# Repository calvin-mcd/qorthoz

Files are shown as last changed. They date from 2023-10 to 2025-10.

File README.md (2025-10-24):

# qorthoz

qorthoz is an ortholinear 10.25u qaz compatible pcb with usb c and jst ports for case compatibility, rgb breakout strip and 6 additional pins for switch or rotary extensions.

## Layout

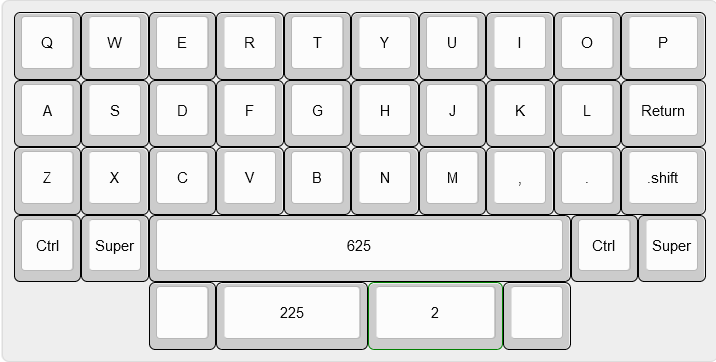
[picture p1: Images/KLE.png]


## Pictures

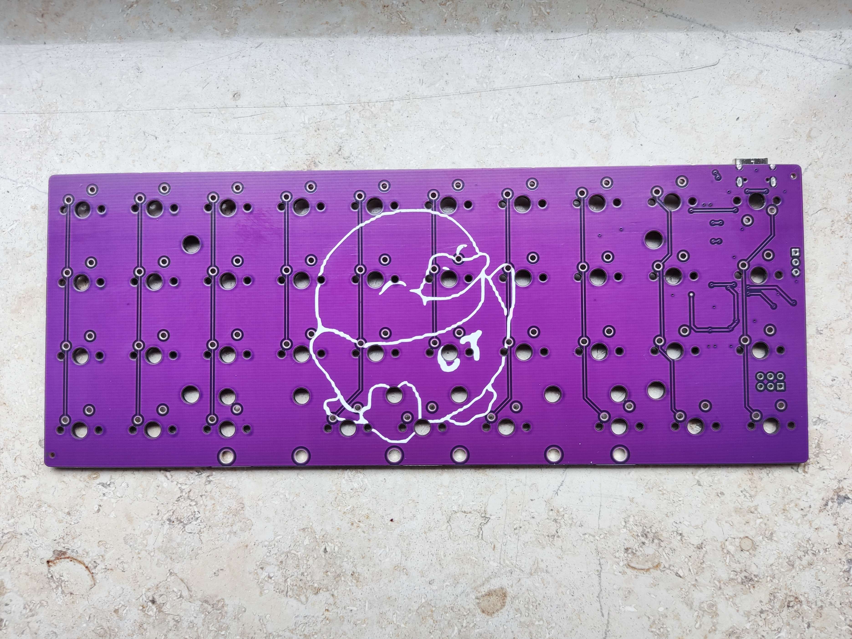
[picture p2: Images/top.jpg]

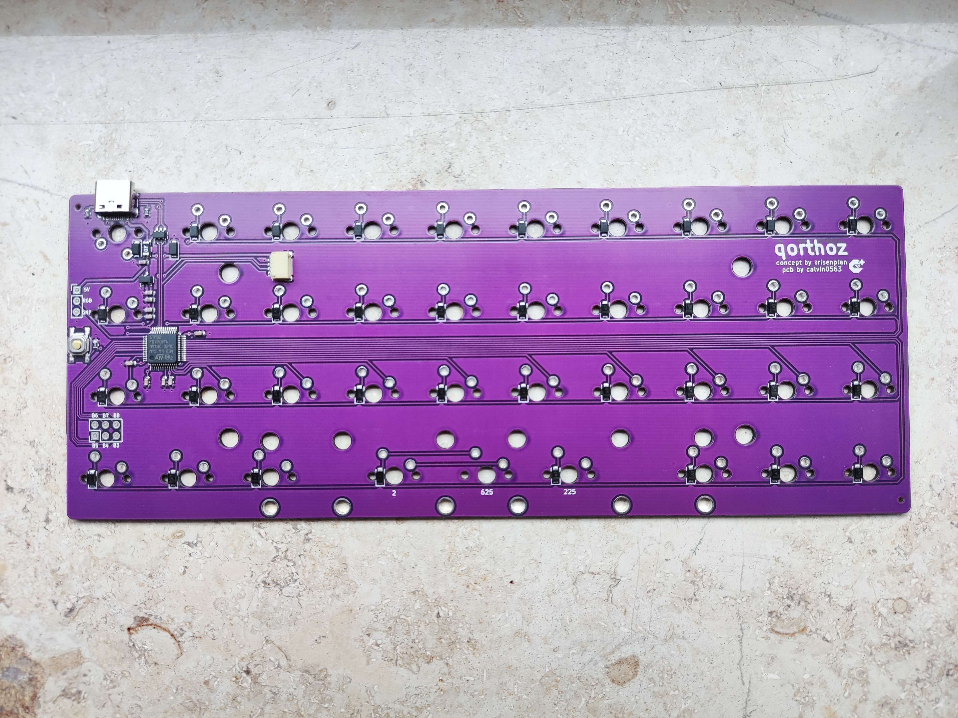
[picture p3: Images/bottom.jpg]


## Firmware

Firmware is written for vial and the source code is provided for edits.

## RGB Strip

Please note that the PCB is using a STM32 MCU which runs on 3v3 logic. Using a 5V rgb strip can sometimes interfere with the 3v3 Data Signal from the MCU. If you use a 5V rgb strip solder Data IN and GND to the beginning of the strip but *DO NOT* solder power to the beginning but anywhere else on the strip. This should be enough to avoid 5V Power interference with the 3v3 Data IN.

## Disclaimer

This PCB has been fully tested and is confirmed to work. However, no-one involved in this project is responsible for any usage issues that may arise. Order at your own risk. Feel free to edit, modify and otherwise utilise these files.

## License

This project is released under the GPL v3 License. Please refer to the LICENCE file.

## Credits

This pcb has been made on request kriscovery. Do check out their beautiful qaz and qez compatible cases! https://www.printables.com/@kriscovery

The silkscreen logo has been taken from the german 40s keyboard discord ClackTales!

As always big thanks to the many people who helped me and inspired this board!

Any questions, contact Calvin0563 on Discord.

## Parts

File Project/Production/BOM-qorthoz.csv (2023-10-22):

Comment | Designator | Footprint | LCSC
SKQGABE010 | SW1 | SW_SPST_SKQG_WithoutStem | C115351
1uF | C1,C2,C4 | C_0603_1608Metric | C15849
JST SH | J3 | JST_SH_SM04B-SRSS-TB_1x04-1MP_P1.00mm_Horizontal | C160404
USB_C_Receptacle_USB2.0 | J1 | USB_C_Receptacle_HRO_TYPE-C-31-M-12 | C165948
4.7uF | C3 | C_0603_1608Metric | C19666
10k | R3 | R_0603_1608Metric | C2139679
5k1 | R1,R2 | R_0603_1608Metric | C14677
USBLC6-2SC6 | U1 | SOT-23-6 | C2827654
100nF | C10,C5,C6,C7,C8,C9 | C_0603_1608Metric | C14663
XC6206PxxxMR-Regulator_Linear | U3 | SOT-23 | C5446
D_Small | D1,D10,D11,D12,D13,D14,D15,D16,D17,D18,D19,D2,D20,D21,D22,D23,D24,D25,D26,D27,D28,D29,D3,D30,D31,D32,D33,D34,D35,D36,D37,D38,D4,D5,D6,D7,D8,D9 | D_SOD-123F | C64898
500mA | F1 | Fuse_1206_3216Metric | C70076
SMF9.0CA | D_PWR1 | D_SOD-123 | C707469
STM32F072C8Tx | U2 | LQFP-48_7x7mm_P0.5mm | C81720

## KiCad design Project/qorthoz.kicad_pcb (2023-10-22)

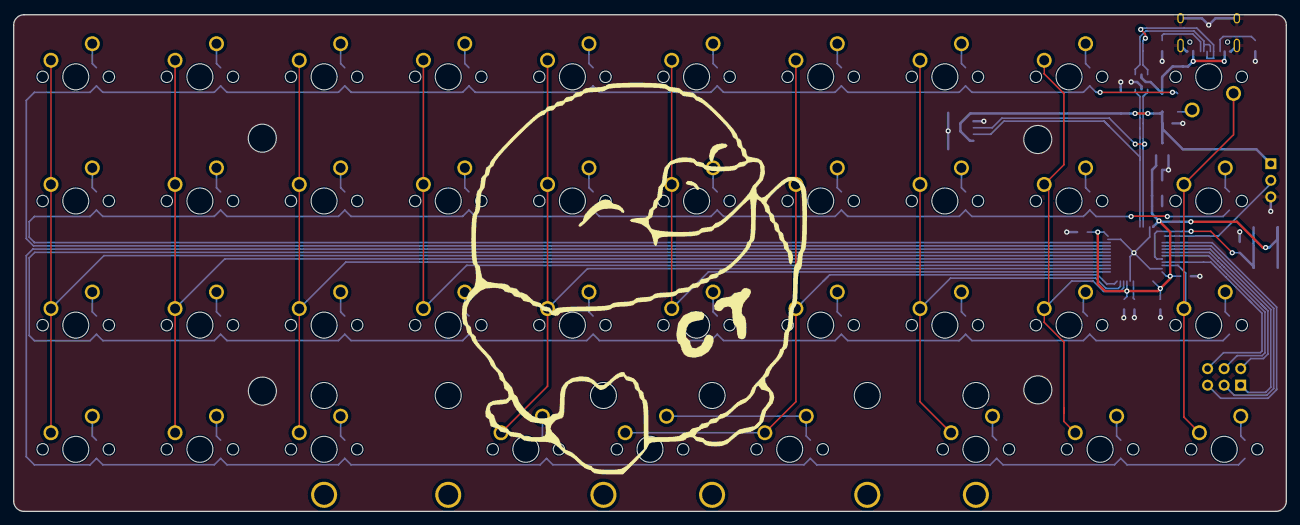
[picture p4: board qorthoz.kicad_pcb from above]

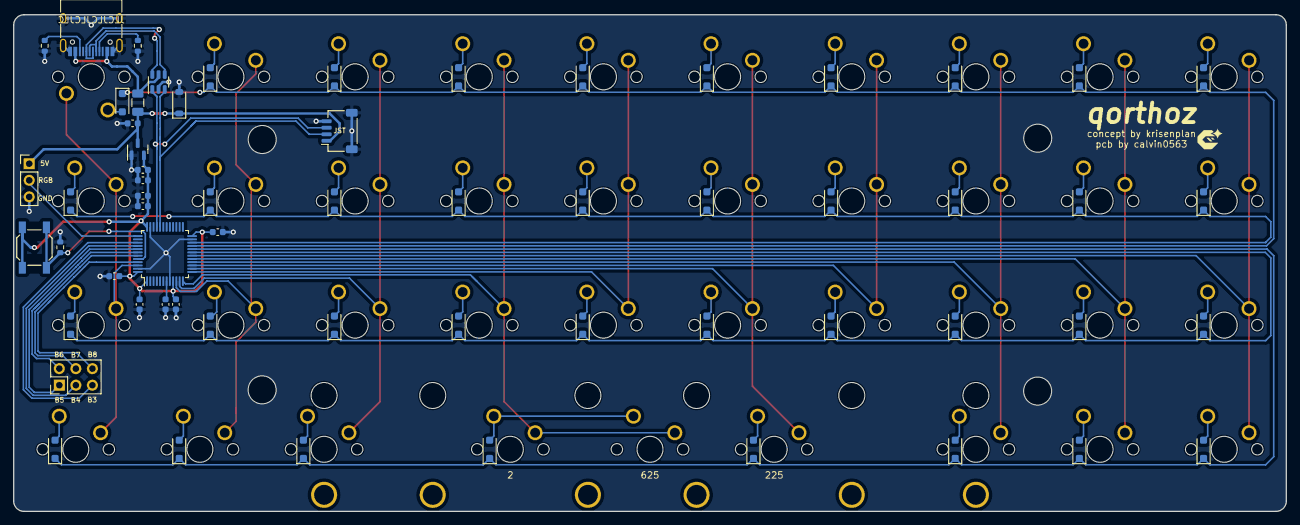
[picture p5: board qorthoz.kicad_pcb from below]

Board: 2 copper layers, 195.3 x 76.2 mm, 103 parts (61 on the bottom side), 71 nets.

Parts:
C1, C2, C4: 1uF; C_0603_1608Metric
C3: 4.7uF; C_0603_1608Metric
C5, C6, C7, C8, C9, C10: 100nF; C_0603_1608Metric
D1, D2, D3, D4, D5, D6, D7, D8, D9, D10, D11, D12, D13, D14, D15, D16, D17, D18, D19, D20, D21, D22, D23, D24, D25, D26, D27, D28, D29, D30, D31, D32, D33, D34, D35, D36, D37, D38: D_Small; D_SOD-123F
D_PWR1: SMF9.0CA; D_SOD-123
F1: 500mA; Fuse_1206_3216Metric
J1: USB_C_Receptacle_USB2.0; USB_C_Receptacle_HRO_TYPE-C-31-M-12
J2: Conn_01x03_Socket; PinHeader_1x03_P2.54mm_Vertical
J3: JST SH; JST_SH_SM04B-SRSS-TB_1x04-1MP_P1.00mm_Horizontal
J4: Conn_01x06; PinHeader_2x03_P2.54mm_Vertical
MX1, MX2, MX3, MX4, MX5, MX6, MX7, MX8, MX9, MX11, MX12, MX13, MX14, MX15, MX16, MX17, MX18, MX19, MX21, MX22, MX23, MX24, MX25, MX26, MX27, MX28, MX29, MX31, MX32, MX33, MX34, MX35, MX36, MX37, MX38, MX39: MX_SW_solder; SW_MX_1u
MX10, MX20, MX30: MX_SW_solder; SW_MX_1.25u
R1, R2: 5k1; R_0603_1608Metric
R3: 10k; R_0603_1608Metric
S1: MX_stab; STAB_MX_P_2.25u
S2: MX_stab; STAB_MX_P_2u
S3: MX_stab; STAB_MX_P_6.25u
SW1: SKQGABE010; SW_SPST_SKQG_WithoutStem
U1: USBLC6-2SC6; SOT-23-6
U2: STM32F072C8Tx; LQFP-48_7x7mm_P0.5mm
U3: XC6206PxxxMR-Regulator_Linear; SOT-23

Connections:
+3V3: C2.2, C3.1, C4.1, C5.1, C6.1, C7.1, C8.1, C9.1, SW1.1, U2.1 (VBAT), U2.9 (VDDA), U2.24 (VDD), U2.36 (VDDIO2), U2.48 (VDD), U3.2 (VO)
+5V: C1.2, D_PWR1.1 (A1), F1.2, J2.1, J3.1, U3.3 (VI)
/CC1: J1.A5 (CC1), R1.1
/CC2: J1.B5 (CC2), R2.1
B3: J4.5, U2.39 (PB3)
B4: J4.3, U2.40 (PB4)
B5: J4.1, U2.41 (PB5)
B6: J4.2, U2.42 (PB6)
B7: J4.4, U2.43 (PB7)
B8: J4.6, U2.45 (PB8)
BOOT0: R3.1, SW1.2, U2.44 (BOOT0)
COL0: MX1.1, MX11.1, MX21.1, MX31.1, U2.18 (PB0)
COL1: MX2.1, MX12.1, MX22.1, MX32.1, U2.17 (PA7)
COL2: MX3.1, MX13.1, MX23.1, MX33.1, U2.16 (PA6)
COL3: MX4.1, MX14.1, MX24.1, U2.15 (PA5)
COL4: MX5.1, MX15.1, MX25.1, MX34.1, U2.14 (PA4)
COL5: MX6.1, MX16.1, MX26.1, U2.13 (PA3)
COL6: MX7.1, MX17.1, MX27.1, MX35.1, MX39.1, U2.12 (PA2)
COL7: MX8.1, MX18.1, MX28.1, MX36.1, U2.11 (PA1)
COL8: MX9.1, MX19.1, MX29.1, MX37.1, U2.10 (PA0)
COL9: MX10.1, MX20.1, MX30.1, MX38.1, U2.46 (PB9)
D_N: J3.2, U1.3 (I/O2), U2.32 (PA11)
D_P: J3.3, U1.1 (I/O1), U2.33 (PA12)
D_USB_N: J1.A7 (D-), J1.B7 (D-), U1.4 (I/O2)
D_USB_P: J1.A6 (D+), J1.B6 (D+), U1.6 (I/O1)
GND: C1.1, C2.1, C3.2, C4.2, C5.2, C6.2, C7.2, C8.2, C9.2, C10.2, D_PWR1.2 (A2), J1.A1 (GND), J1.A12 (GND), J1.B1 (GND), J1.B12 (GND), J1.S1 (SHIELD), J2.3, J3.4, J3.MP (MountPin), R1.2, R2.2, R3.2, U1.2 (GND), U2.8 (VSSA), U2.23 (VSS), U2.35 (VSS), U2.47 (VSS), U3.1 (GND)
NRST: C10.1, U2.7 (NRST)
unnamed: D1.2 (A), MX1.2
unnamed: D2.2 (A), MX2.2
unnamed: D3.2 (A), MX3.2
unnamed: D4.2 (A), MX4.2
unnamed: D5.2 (A), MX5.2
unnamed: D6.2 (A), MX6.2
unnamed: D7.2 (A), MX7.2
unnamed: D8.2 (A), MX8.2
unnamed: D9.2 (A), MX9.2
unnamed: D10.2 (A), MX10.2
unnamed: D11.2 (A), MX11.2
unnamed: D12.2 (A), MX12.2
unnamed: D13.2 (A), MX13.2
unnamed: D14.2 (A), MX14.2
unnamed: D15.2 (A), MX15.2
unnamed: D16.2 (A), MX16.2
unnamed: D17.2 (A), MX17.2
unnamed: D18.2 (A), MX18.2
unnamed: D19.2 (A), MX19.2
unnamed: D20.2 (A), MX20.2
unnamed: D21.2 (A), MX21.2
unnamed: D22.2 (A), MX22.2
unnamed: D23.2 (A), MX23.2
unnamed: D24.2 (A), MX24.2
unnamed: D25.2 (A), MX25.2
unnamed: D26.2 (A), MX26.2
unnamed: D27.2 (A), MX27.2
unnamed: D28.2 (A), MX28.2
unnamed: D29.2 (A), MX29.2
unnamed: D30.2 (A), MX30.2
unnamed: D31.2 (A), MX31.2
unnamed: D32.2 (A), MX32.2
unnamed: D33.2 (A), MX33.2
unnamed: D34.2 (A), MX34.2
unnamed: D35.2 (A), MX35.2, MX39.2
unnamed: D36.2 (A), MX36.2
unnamed: D37.2 (A), MX37.2
unnamed: D38.2 (A), MX38.2
RGB: J2.2, U2.37 (PA14)
ROW0: D1.1 (K), D2.1 (K), D3.1 (K), D4.1 (K), D5.1 (K), D6.1 (K), D7.1 (K), D8.1 (K), D9.1 (K), D10.1 (K), U2.21 (PB10)
ROW1: D11.1 (K), D12.1 (K), D13.1 (K), D14.1 (K), D15.1 (K), D16.1 (K), D17.1 (K), D18.1 (K), D19.1 (K), D20.1 (K), U2.22 (PB11)
ROW2: D21.1 (K), D22.1 (K), D23.1 (K), D24.1 (K), D25.1 (K), D26.1 (K), D27.1 (K), D28.1 (K), D29.1 (K), D30.1 (K), U2.19 (PB1)
ROW3: D31.1 (K), D32.1 (K), D33.1 (K), D34.1 (K), D35.1 (K), D36.1 (K), D37.1 (K), D38.1 (K), U2.20 (PB2)
VBUS: F1.1, J1.A4 (VBUS), J1.A9 (VBUS), J1.B4 (VBUS), J1.B9 (VBUS), U1.5 (VBUS)
